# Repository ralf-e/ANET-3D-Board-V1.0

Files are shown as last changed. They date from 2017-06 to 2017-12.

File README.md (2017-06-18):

## ANET-3D-Board-V1.0

Only a traced circuit diagram of the ANET A6 / A8 board, hopefully error free.

For information purposes....

- Anet 3D Printer Board V1.0 Schematic (Anet A6 / A8)
- Anet 3D Printer LCD12864 Graphics LCD Board Schematic (Anet A6 / A8)
- Anet 3D Printer LCD2004 Keypad LCD Board Schematic (draft) (ANET A8)
- Mosfet Board Schematic

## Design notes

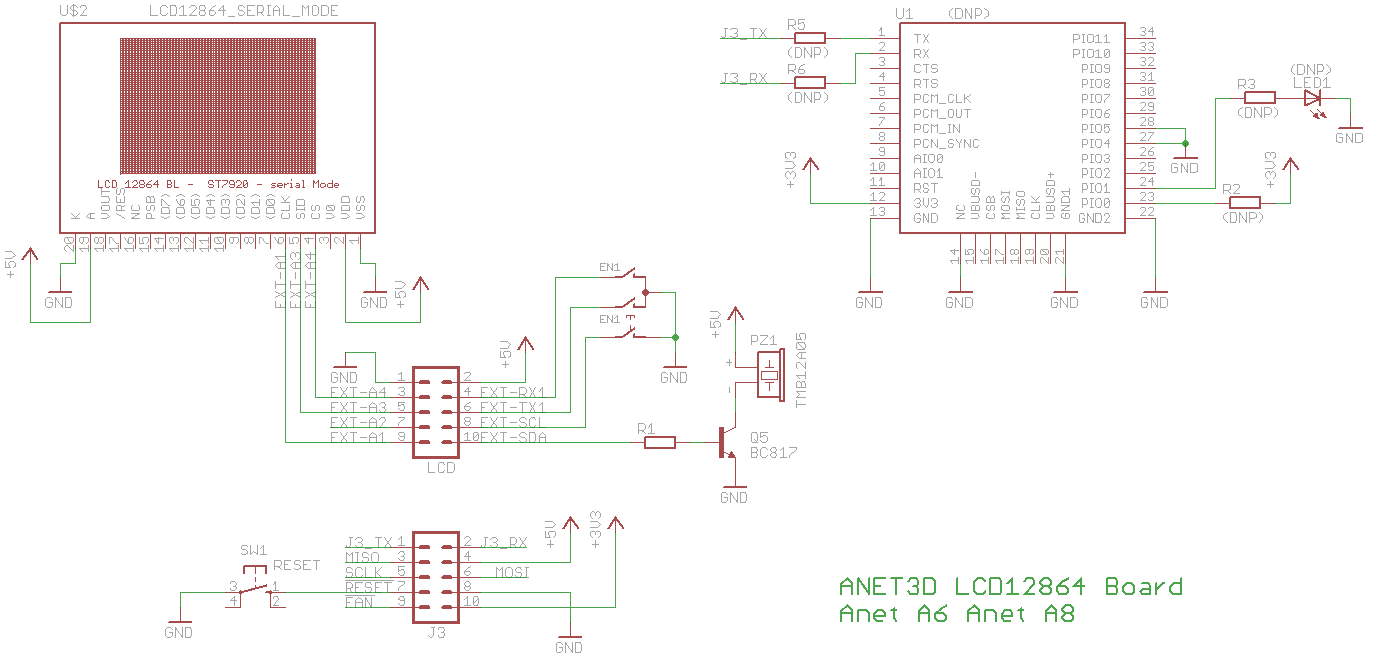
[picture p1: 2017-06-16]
ANET3D_LCD12864_Board_Schematic.png

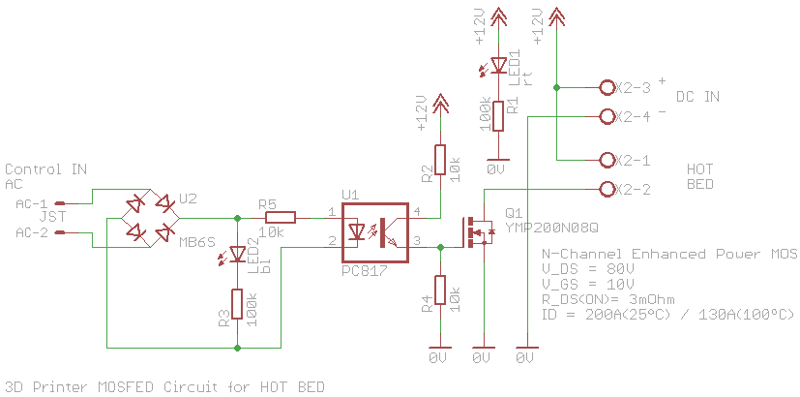
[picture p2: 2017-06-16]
Mosfet_addon_Board_Schematic.png

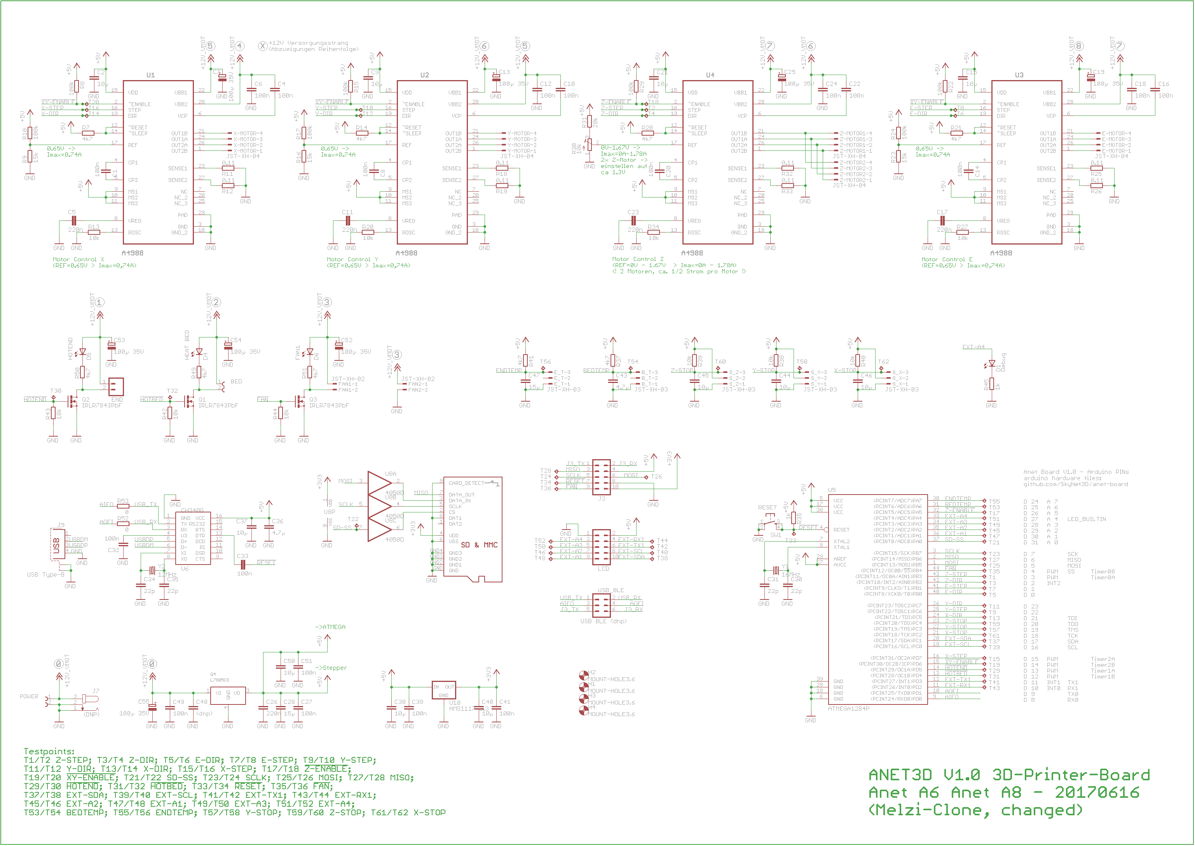
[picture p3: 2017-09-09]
ANET3D_Board_Schematic.png

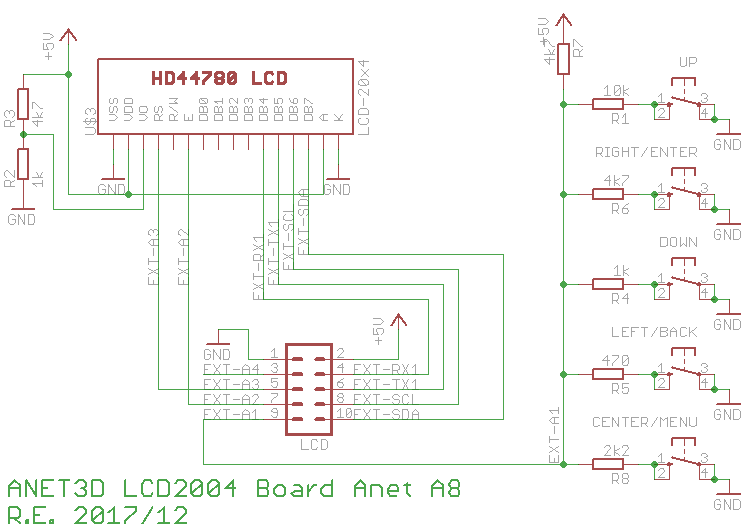
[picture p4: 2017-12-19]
ANET3D_LCD2004_board.png

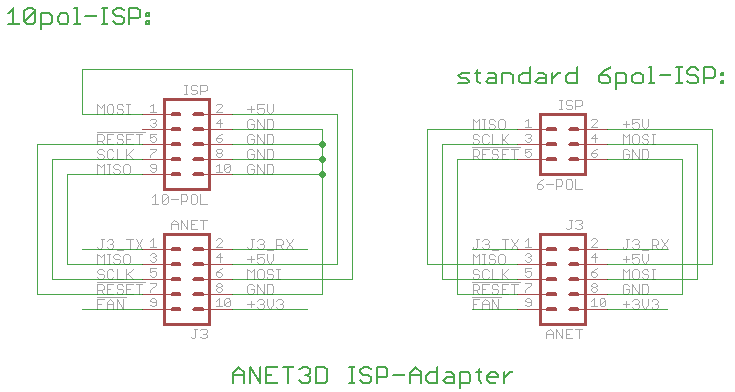
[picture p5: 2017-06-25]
ANET3D-ISP-Adapter.png

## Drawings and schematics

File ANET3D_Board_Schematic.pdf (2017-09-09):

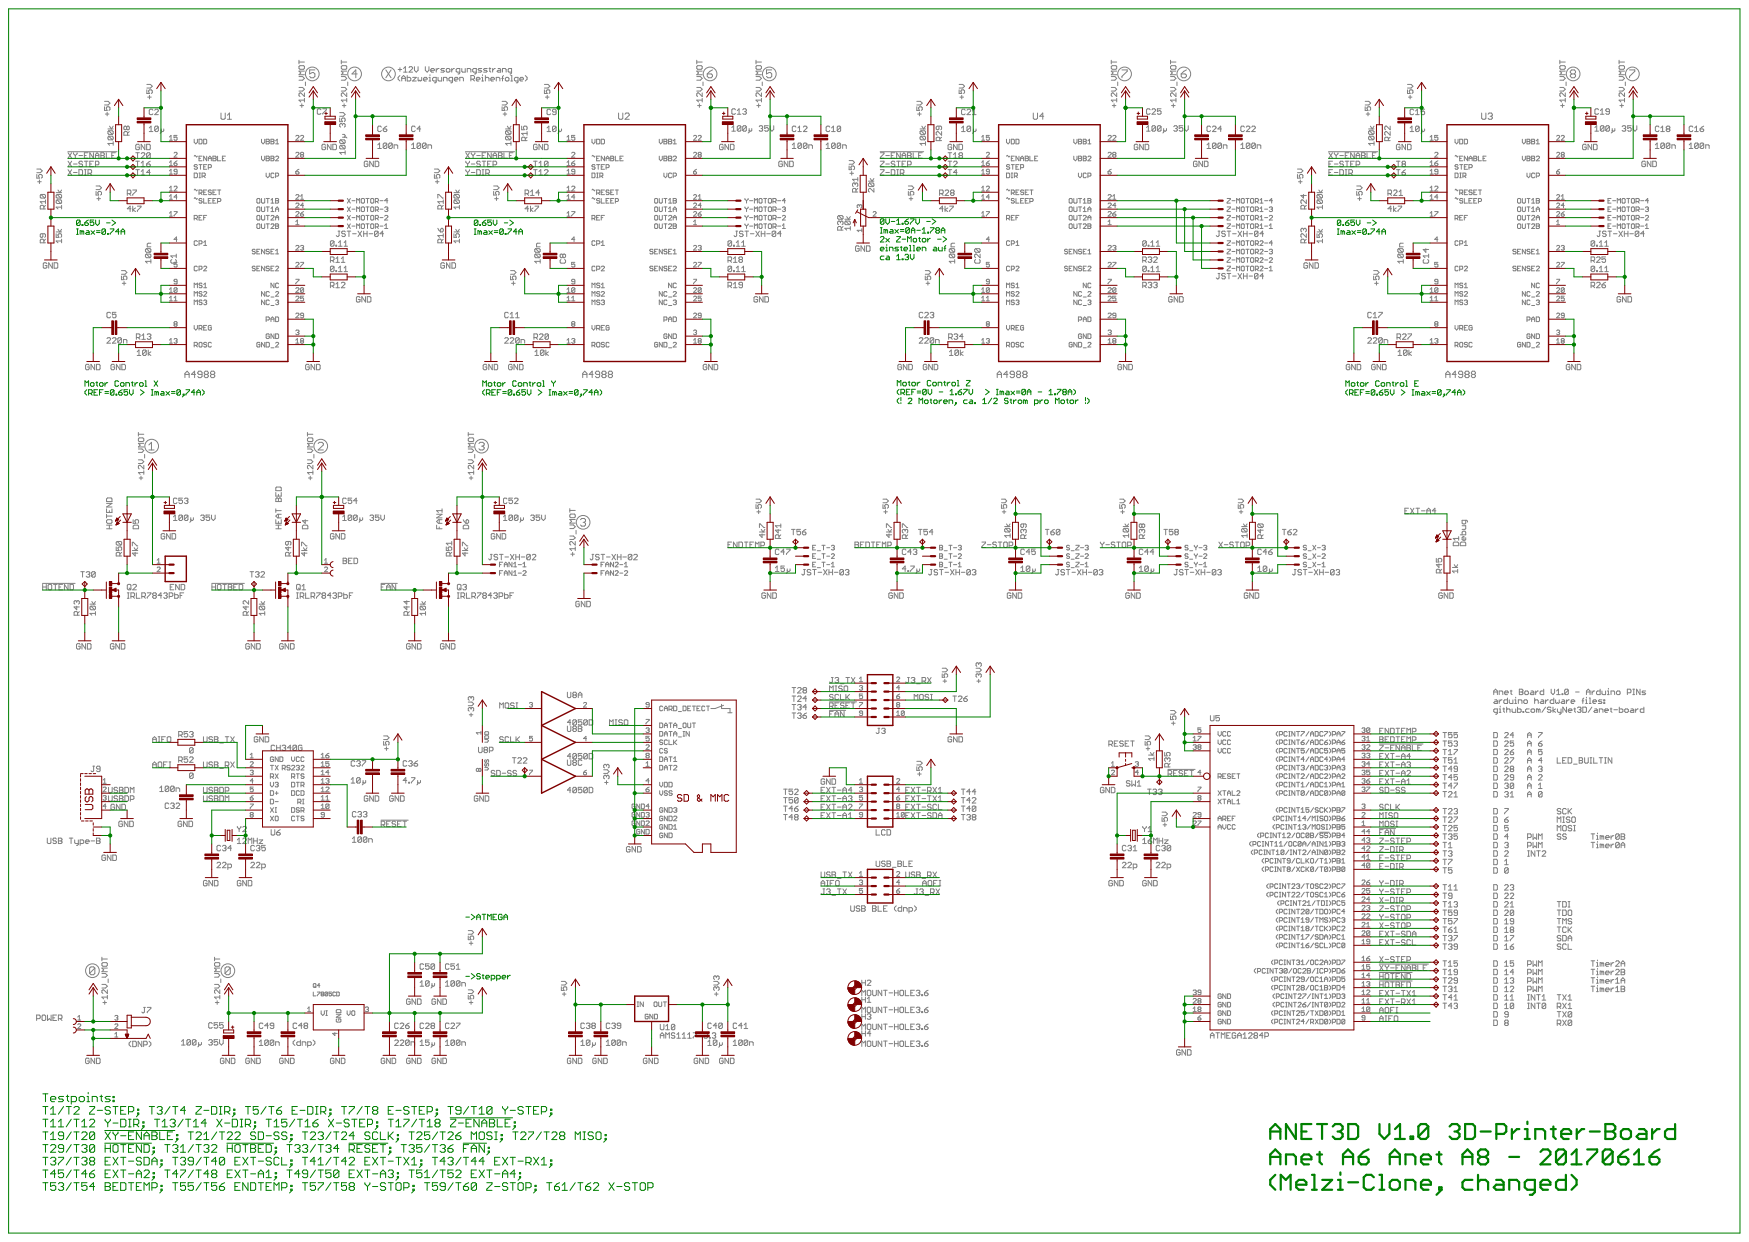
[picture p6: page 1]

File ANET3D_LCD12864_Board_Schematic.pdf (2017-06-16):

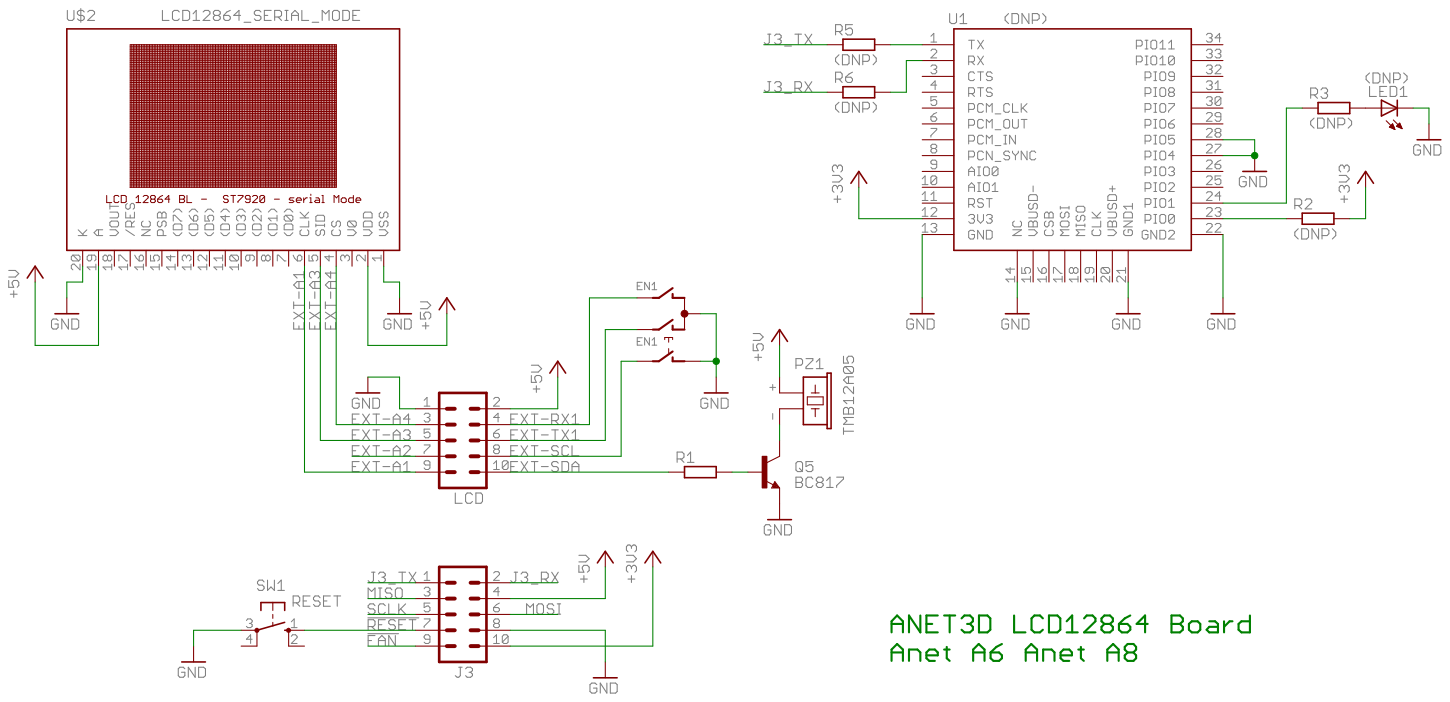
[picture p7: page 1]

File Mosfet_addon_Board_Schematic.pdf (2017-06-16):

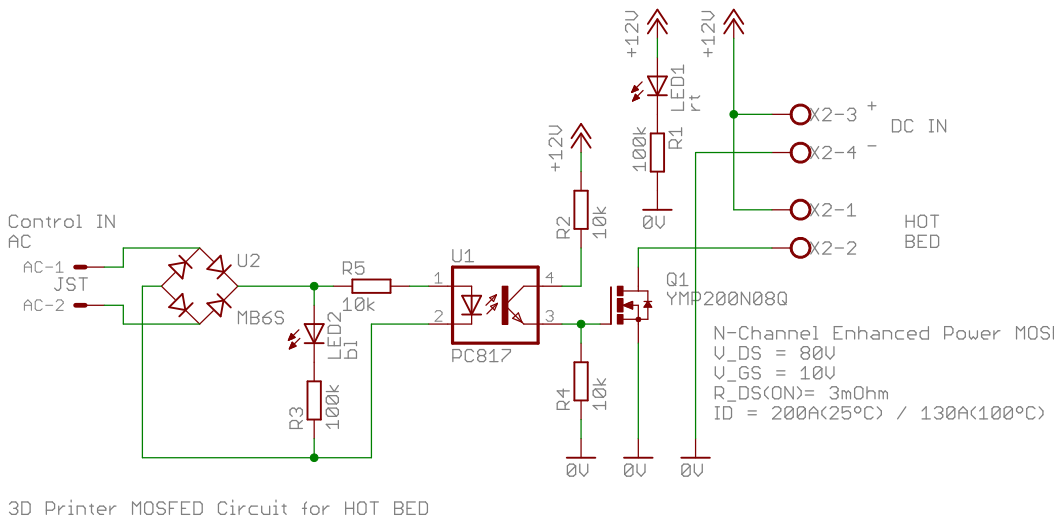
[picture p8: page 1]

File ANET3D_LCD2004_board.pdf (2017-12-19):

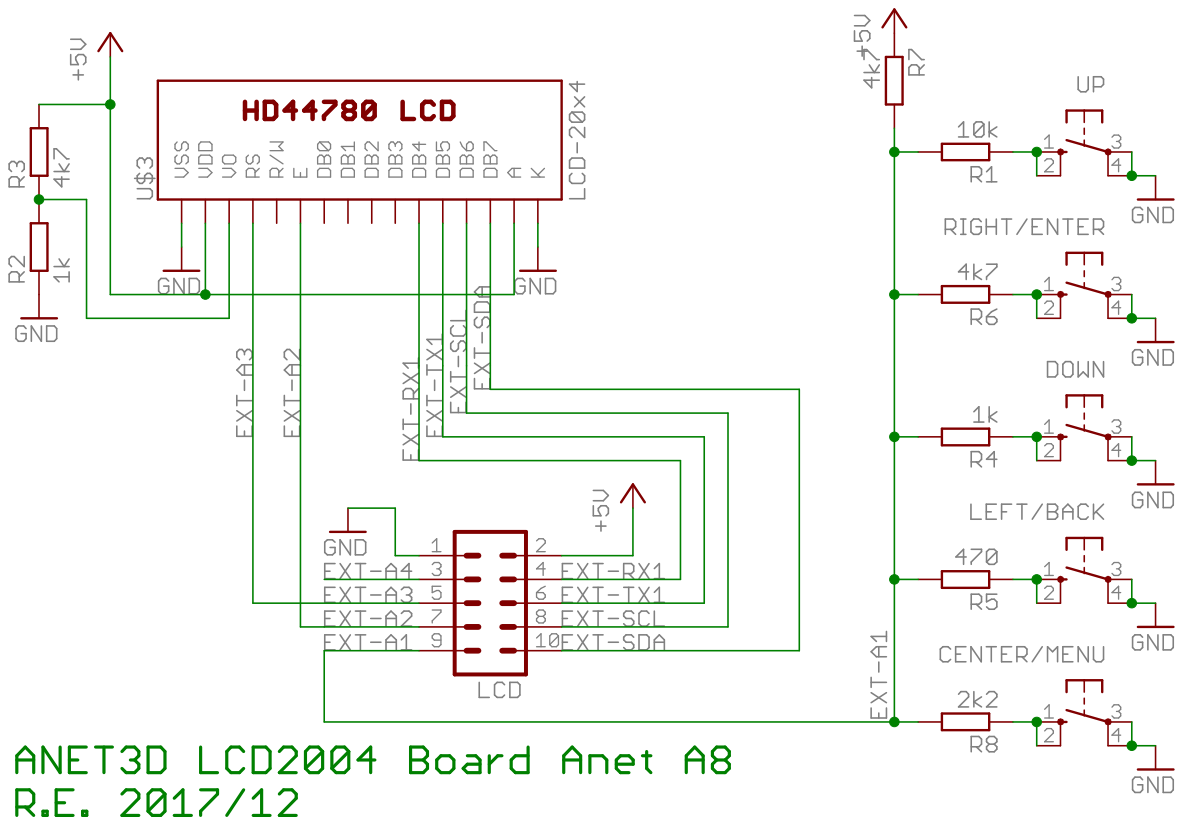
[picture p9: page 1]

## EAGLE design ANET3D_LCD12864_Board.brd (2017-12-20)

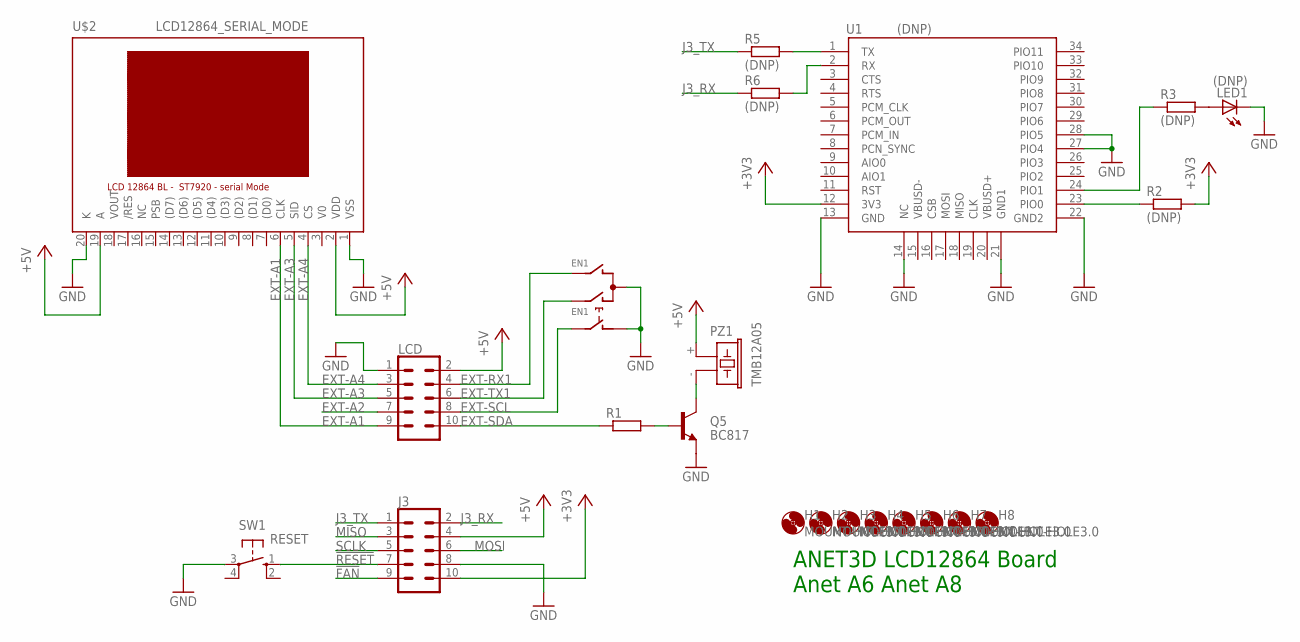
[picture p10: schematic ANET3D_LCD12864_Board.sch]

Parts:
EN1: EC12E_SW; ALPS_EC12E_SW
H1, H2, H3, H4, H5, H6, H7, H8: MOUNT-HOLE3.0; 3,0
J3: CONN_05X2SHD_SMD; 2X5-SHROUDED_SMD
LCD: CONN_05X2SHD_SMD; 2X5-SHROUDED_SMD
LED1: (DNP); CHIPLED_0805
PZ1: TMB12A05; F/CM12P
Q5: BC817; SOT23-BEC
R1: R-EU_R0805; R0805
R2, R3, R5, R6: (DNP); R0805
SW1: RESET; B3F-40XX
U1: (DNP); BLUETOOTH_SMD
U$2: LCD12864_SERIAL_MODE; LCD12864

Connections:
!FAN: J3.9
!RESET: J3.7, SW1.1 (S)
+3V3: J3.10, R2.2, U1.12 (3V3)
+5V: J3.4, LCD.2, PZ1.+ (1), U$2.2 (VDD), U$2.19 (A)
EXT-A1: LCD.9, U$2.6 (CLK)
EXT-A2: LCD.7
EXT-A3: LCD.5, U$2.5 (SID)
EXT-A4: LCD.3, U$2.4 (CS)
EXT-RX1: EN1.B, LCD.4
EXT-SCL: EN1.E (2), LCD.8
EXT-SDA: LCD.10, R1.1
EXT-TX1: EN1.A, LCD.6
GND: EN1.C, EN1.D (1), J3.8, LCD.1, LED1.C, Q5.E, SW1.3, U1.13 (GND), U1.14 (NC), U1.21 (GND1), U1.22 (GND2), U1.27 (PIO4), U1.28 (PIO5), U$2.1 (VSS), U$2.20 (K)
J3_RX: J3.2, R6.1
J3_TX: J3.1, R5.1
MISO: J3.3
MOSI: J3.6
unnamed: Q5.B, R1.2
unnamed: R3.1, U1.24 (PIO1)
unnamed: PZ1.- (2), Q5.C
unnamed: LED1.A, R3.2
unnamed: R5.2, U1.1 (TX)
unnamed: R6.2, U1.2 (RX)
unnamed: R2.1, U1.23 (PIO0)
SCLK: J3.5

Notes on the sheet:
ANET3D LCD12864 Board Anet A6 Anet A8

Board: 2 copper layers, 22 parts (10 on the bottom side), 20 nets, no tracks yet.

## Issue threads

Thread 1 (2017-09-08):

Value for R30

gregory-whaley, 2017-09-08:
I think the value for potentiometer R30 should be 50K rather than 10K.

My board has a fixed resistor instead of the pot for R30.

Thanks for sharing the schematic.

ralf-e, 2017-09-09:
The value 10k for potentiometer R30 is correct. R31 100k is wrong in the circuit diagram, the correct value for R31 is 20k. The two resistors form an adjustable voltage divider 20k / 10k ... 30k / 0k at 5V = 1.67V-0V

gregory-whaley, 2017-09-09:
Very good.  Thanks!

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

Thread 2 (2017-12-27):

Strange pinout for LCD connector to LCS12864 board

TD-er, 2017-12-27:
I was just looking into the schematics and they are quite interesting  and informative.
But I was wondering if either the labeling or the pinout of the pins to the LCD connector on the LCD12864 board are correct?
EXT-RX1 and EXT-TX1 are said to be connected to the encoder.
EXT-SCL to the reset switch and EXT-SDA to the speaker.

And the EXT-A1 , -A3 and -A4 do the actual display communication.
It looks like the pinout is correct, but then where are the labels coming from?

ralf-e, 2017-12-27:
These labels are the Arduino-"pins"
https://github.com/SkyNet3D/anet-board/blob/master/hardware/anet/avr/variants/sanguino/pins_arduino.h

Closed 2017-12-27.

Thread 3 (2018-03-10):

U1 on ANET3D_LCD12864_Board

pecirep, 2018-03-10:
What is U1 on the ANET3D_LCD12864_Board for? I thought it was meant for an SD card slot but apparently not, since besides power and an LED only RX and TX are connected, an SD would need at least 2 more "data" pins, even for SPI mode (MISO, MOSI, CLK, CS).

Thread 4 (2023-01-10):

I'm having problems with z_endstop

Eugenio-Andreola, 2023-01-10:
Hello folks, I'm having problems with the endstop of the Z axis, it is always active, I saw that I would need to redo the soldering of the capacitor (R39), but if I change it, what is the most correct specification for it?

Ceramic capacitor Smd 10uf 50v 20% X7r 1.7mm X 0.8mm

Ceramic capacitor Smd 10uf 50v 10% X7r1210 3.2x2.5mm

Or would there be another one more correct?

Taking advantage of this, I'm thinking of replacing the C45 resistor as well.

Remembering that I know practically nothing about electronics and soldering ehehe

Thanks for the help.

hannesweisbach, 2023-01-10:
Hey Eugenio,

R usually designates resistors, not capacitors. According to the schematic R39 has a value of 10k. Run-of-the mill resistors usually have a voltage rating of 50V, which is more than enough for this application. If you have any other resistors handy, I'd say anything from 4.7k to 47k is probably ok. The higher the resistance, the more suceptible to noise the endstop will be. 10k is good tradeoff between current consumption and noise susceptibility.

Best,
Hannes

Eugenio-Andreola, 2023-01-11:
Oops, I messed up with the information...
How are you, Hannesweisbach?
I was really referring to the capacitor (C45) and not the resistor (R39) which apparently is not showing any problems until now. But I'm thinking of changing the two, regarding the Capacitor, would you know how to help me and understand which would be the best?
In the specifications they have some data that I don't know what the percentage means: Ceramic capacitor Smd 10uf 50v 20% X7r
Ceramic capacitor Smd 10uf 50v 10% X7r, would it mean their accuracy?
And this X7r, would it be some information that I would need to pay attention to in order to choose the correct one?

hannesweisbach, 2023-01-12:
Hey,

No problem. I had a look at the schematic again. In my opinion C45 is optional, unless you're having problems with your end stop, like "ghost triggering", when your printer says your end stop activated when it clearly didn't.
The capacitor is purely to remove noise from the signal line. IMHO 10u are *way* too much. I think 10nF are more suitable. The reason is the capacitor is charged to 5V through R39 and then the end stop switch shorts out C45. The (relatively) high and sudden current from a 10u ceramic capacitor will wear out and break the contacts in the end stop (especially cheap ones).
Think contacts or distributors in the ignition of older cars.
This is much less of a problem if you have solid state end stop, such as optical or magnetic (hall effect) ones.

The letters such as X7R and Y5V refer the electrolytic used in the cap. X7R is better than Y5V. NP0 is better still (and more expensive). Y5V is sufficient for this application, but since Y5V is the same price as X7R, especially in onesie quantities, it doesn't matter. (X7R used to be more expensive than Y5V). TLDR: X7R is ok.

The percentage means how much the capacitance can vary under nominal conditions (normal temperature, "normal" voltage (depends on the type, usually they are measured at 0.6V or something?). So let's say 100nF 20% can go from 80nF to 120nF (or was it 80nF to 100nF, could be the percentage is only how much less the capacitance could be). Capacitance also reduces with voltage and temperature. At nominal voltage it may very well be the capacitor has only 20-40% of it's nominal capacitance left.
TLDR: In this application it doesn't matter. Choose the cheapest.

I'd use 10-47nF, Y5V or X7R (or some unrated crap in my leftover box), 10V+ rating. 50V is probably overrated too. You can also try if it work without this cap. This depends on your steppers, their configuration, wire routing etc.

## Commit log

2017-06-16 added .pdf .png
    [Mosfet_addon_Board.sch]
2017-06-16 Arduino Pin definition added (for NAET 3D Board LED D1 (LED_BUILTIN))
    [ANET3D_Board.sch]
2017-06-18 ANET A8 Keypad LCD added
    [ANET3D_LCD2004_board.sch]
2017-06-18 LCD2004 keypad resistor values
    [ANET3D_LCD2004_board.sch]
2017-06-25 added ANET ISP-Adapter
    [ANET3D-ISP-Adapter.sch]
2017-09-09 value R31 corrected
    [ANET3D_Board.sch, ANET3D_LCD12864_Board.sch]
2017-12-19 Anet3d LCD2004 Resistor values corrected
    [ANET3D_LCD2004_board.sch]
2017-12-20 R/W corrected
    [ANET3D_LCD12864_Board.brd]

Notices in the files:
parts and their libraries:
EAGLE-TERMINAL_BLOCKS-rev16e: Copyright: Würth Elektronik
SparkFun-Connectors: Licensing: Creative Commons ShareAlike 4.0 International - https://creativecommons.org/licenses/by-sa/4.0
